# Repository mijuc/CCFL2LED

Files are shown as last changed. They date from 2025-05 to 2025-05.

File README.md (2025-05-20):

# CCFL2LED

Hi! I'm working on the R&D side of the Поново project. Through our initiative, where we upcycle old electronic devices in exchange for tree seedlings, we’ve noticed that LCD monitors are among the most common items ending up in landfills — and in our repair center as well.

Interestingly, the majority of these monitors share the same issue: the backlight. Most of them use CCFL (cold cathode fluorescent lamp) backlighting, which is often partially or completely non-functional.

As project volunteers, we concluded that replacing the CCFL lamps is not cost-effective. Instead, we aim to modernize these monitors by upgrading them to LED backlighting.

If there are any PCB design or engineering experts among you who would like to provide feedback on the design and concept — we would really appreciate it! We’d also be grateful if you could support our project by sharing it on social media or donating via [OpenCollective](https://opencollective.com/ponovo).

# Why is this change so important?

CCFL lamps are extremely harmful to the environment if broken, as they contain mercury, various metals, and plastics. They also have a significantly shorter lifespan and consume more power compared to LED technology (power consumption can be reduced by up to 40%). Controlling CCFLs requires complex electronics to drive an inverter that can generate up to 2kV AC. These circuits can degrade over time, leading to various failures, such as capacitor damage or degradation, which further impacts device operation.

Additionally, over time, CCFLs tend to yellow, giving the display a reddish or pinkish tint. That’s where LED strips come in — they are very easy to use, safer, more reliable, more available, cheaper, and longer-lasting.

# What are the results after the replacement?

The results were truly unexpected. We didn’t anticipate such a significant improvement in image quality — the colors became much more vibrant. There are no dark areas, and the light is evenly distributed across the screen. Efficiency increased, and power consumption was reduced by 30%.

# Plan and idea
The plan is to create an open-source, universal modular board for displays (composed of multiple parts/modules). This board currently combines several modules. For now, this is sufficient for us to recycle and upgrade monitors that arrive for recycling through the project [Поново](https://www.linkedin.com/company/ponovo/).

Here are picture of the working prototype (with the same chip tested on a 19", 22" and 24" display):

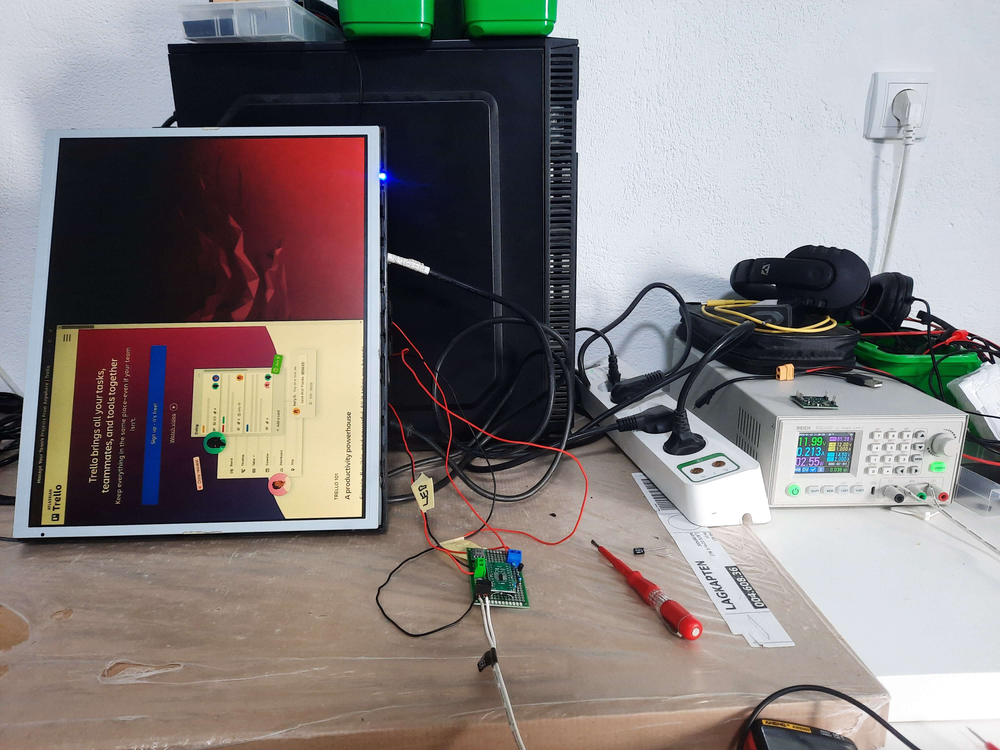
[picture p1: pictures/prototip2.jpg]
prototip2
 

# About the Board

**Warning: This particular board has not yet been fully tested! It has only been tested using separate modules.**
 * **Power supply:** USB-C PD 12V or 12V 3A barrel jack (center-positive)
 * **LED driver:** PT4115 with parallel current sense resistors, calculated based on the [datasheet](https://www.lcsc.com/datasheet/lcsc_datasheet_1810121830_PowTech-CR-PowTech-Shanghai-PT4115B89E_C84512.pdf)
 * **Buck converter:** AP62201 ([datasheet](https://www.lcsc.com/datasheet/lcsc_datasheet_2308101545_Diodes-Incorporated-AP62201WU-7_C3194236.pdf))
 * **USB Type-C PD controller:** CH224K ([datasheet](https://www.laskakit.cz/user/related_files/ch224ds1.pdf))
<p align="center">
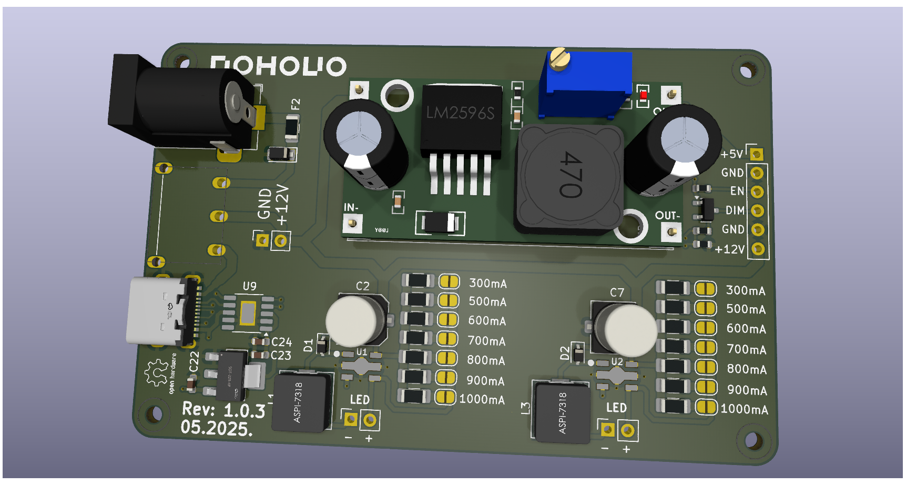
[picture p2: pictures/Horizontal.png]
  
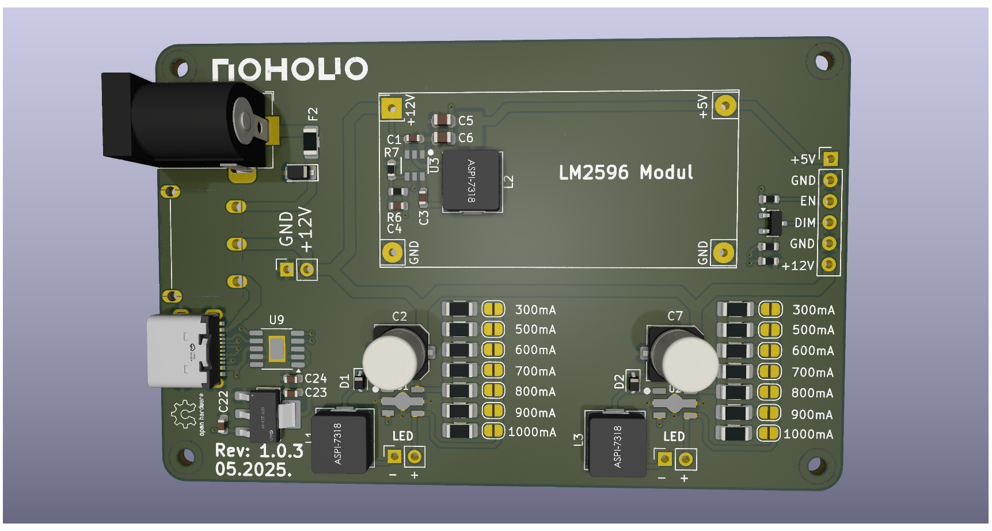
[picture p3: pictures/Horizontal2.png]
  
</p>

# Choosing an LED strip

We recommend using a strip with 120 LEDs per meter. It’s also possible to implement the mod with a 60 LEDs/m strip, but the brightness will be noticeably lower. LED's must be 6500k color. Testing of different sizes of LED strip is in progress...
# Power Supply

A maximum of 36W is required (typically around 30W depending on screen size and number of LEDs). There are two input options, selectable via a switch. The USB-C Power Delivery input uses the CH224K chip configured for a 12V output, so it's crucial to ensure that your adapter supports 12V PD — otherwise, it will not work. The second input is a standard DC jack (5.5mm outer, 2.0mm inner, center-positive) with a 12V power supply.

# LED Driver

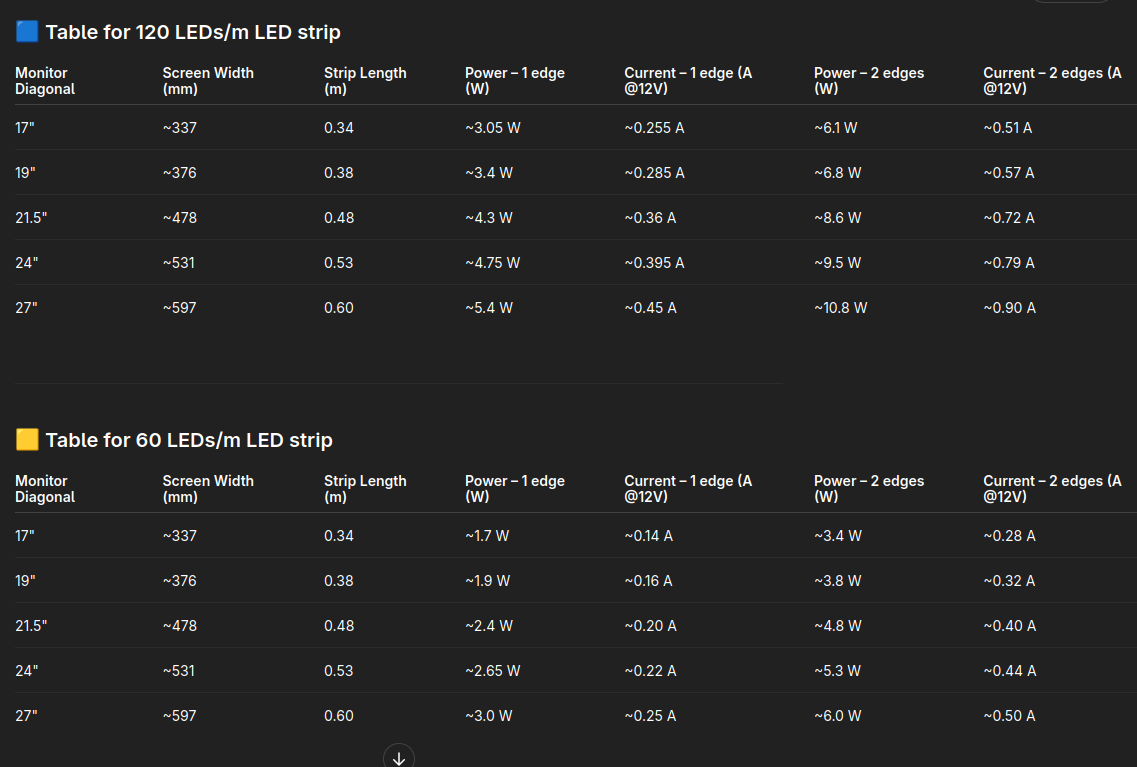
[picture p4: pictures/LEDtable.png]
TABLE
One PT4115 driver is used per side (especially important for larger screen sizes). Below is a table showing LED strip power consumption.  
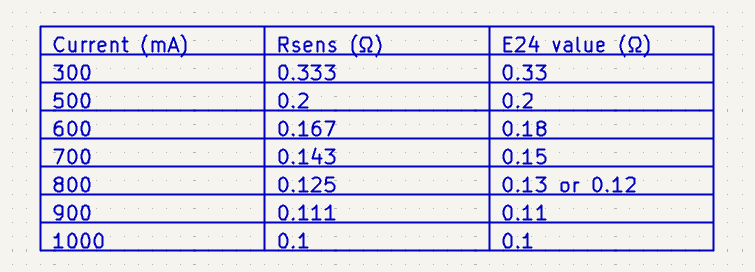
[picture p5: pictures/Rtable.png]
TABLE
Also included is a table with required resistor values. 
# Buck Converter

There are two options for the buck converter:
* Use a prebuilt LM2596 module and connect it to the board.
* Use the integrated circuit on the board — the AP62201WU-7 chip, which provides 5V for the logic board.
The maximum output power required is up to 8W at 5V.

# Modification
  **Warning: Before starting, make sure to clean the workspace and put on gloves!!!**
  
The steps we will go through in this process are:
* Carefully open the display and separate the backlight and the panel from the electronic boards.
* Continue opening the display and separate the panel from the housing, placing it in a clean area (be extremely careful during this step).
* Remove the diffusers, being careful not to mix up their order.
* Replace the CCFL (cold cathode fluorescent lamps), remove them, measure the appropriate length of LED strips, solder 30-40 cm of wire to them, and install them in place of the CCFL, then test them.
* Reinstall the diffusers and test the LED strips again to check if the diffusers have been properly returned to their place.
* Reinstall the panel (check that it is completely clean) and close that part of the display.
* Connect the LED backlight to the power supply board and link it to the display logic board.
* Test the monitor to check if all functions are working on the On-Screen Display (OSD) menu.
* Close the display and put it into operation.
- - - - 
1. **Carefully open the display and separate the backlight and the panel from the electronic boards.**

   -Be careful with the LVDS cable going to the panel
   
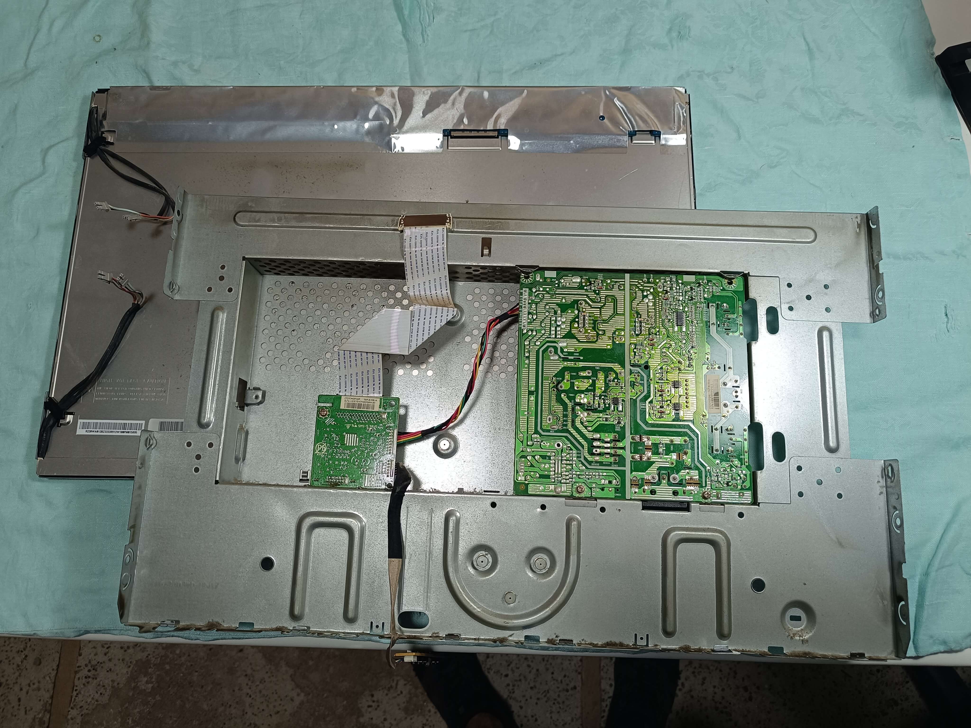
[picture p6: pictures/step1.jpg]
step1


2. **Continue opening the display and separate the panel from the housing, placing it in a clean area (be extremely careful during this step).**

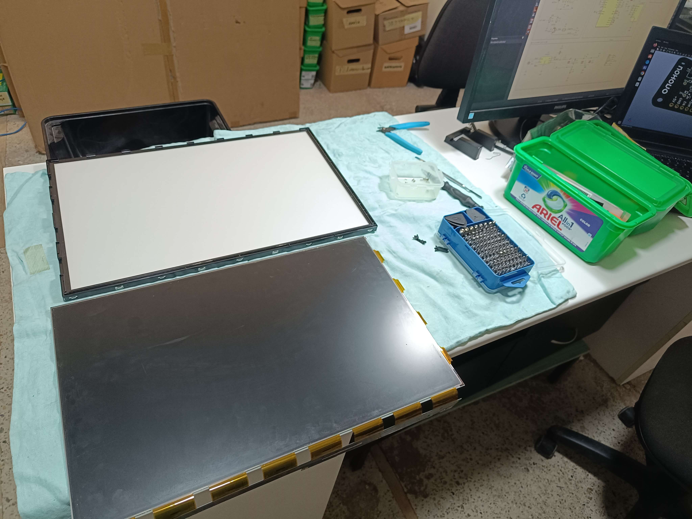
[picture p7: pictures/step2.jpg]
step2


3. **Remove the diffusers, being careful not to mix up their order.**

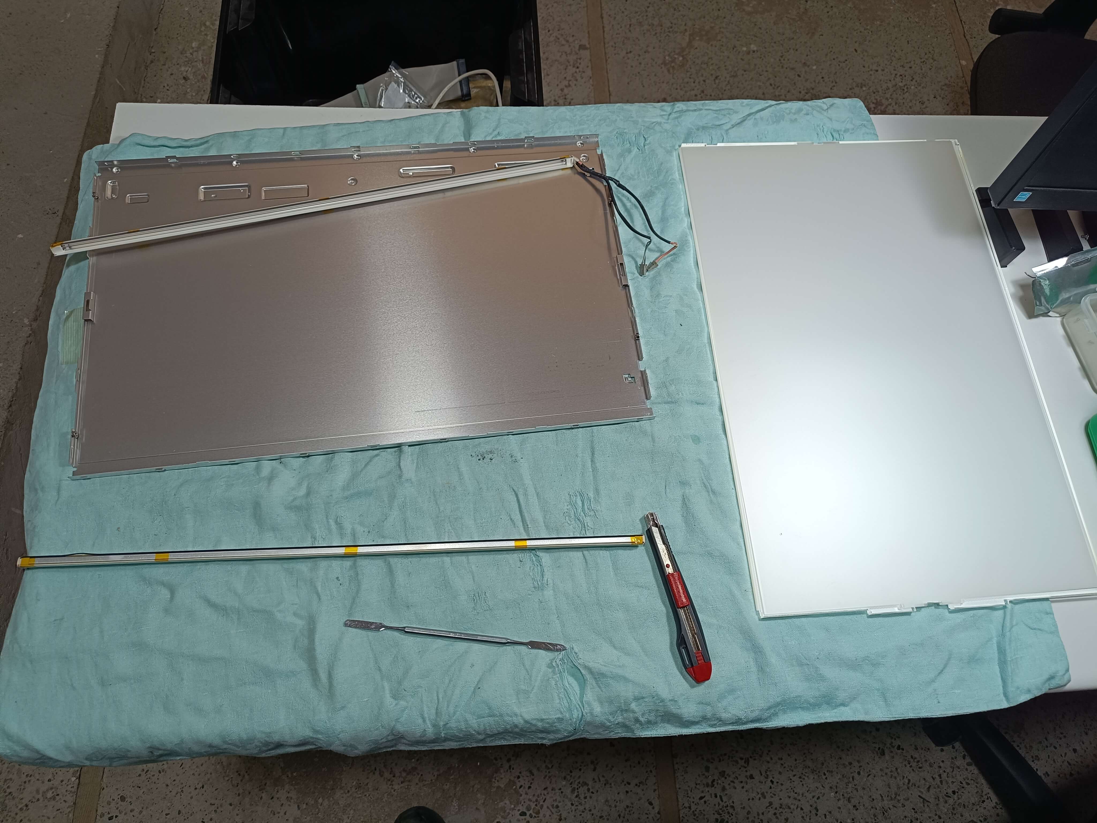
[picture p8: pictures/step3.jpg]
step3


4. **Replace the CCFL (cold cathode fluorescent lamps), remove them, measure the appropriate length of LED strips, solder 30-40 cm of wire to them, and install them in place of the CCFL, then test them.**

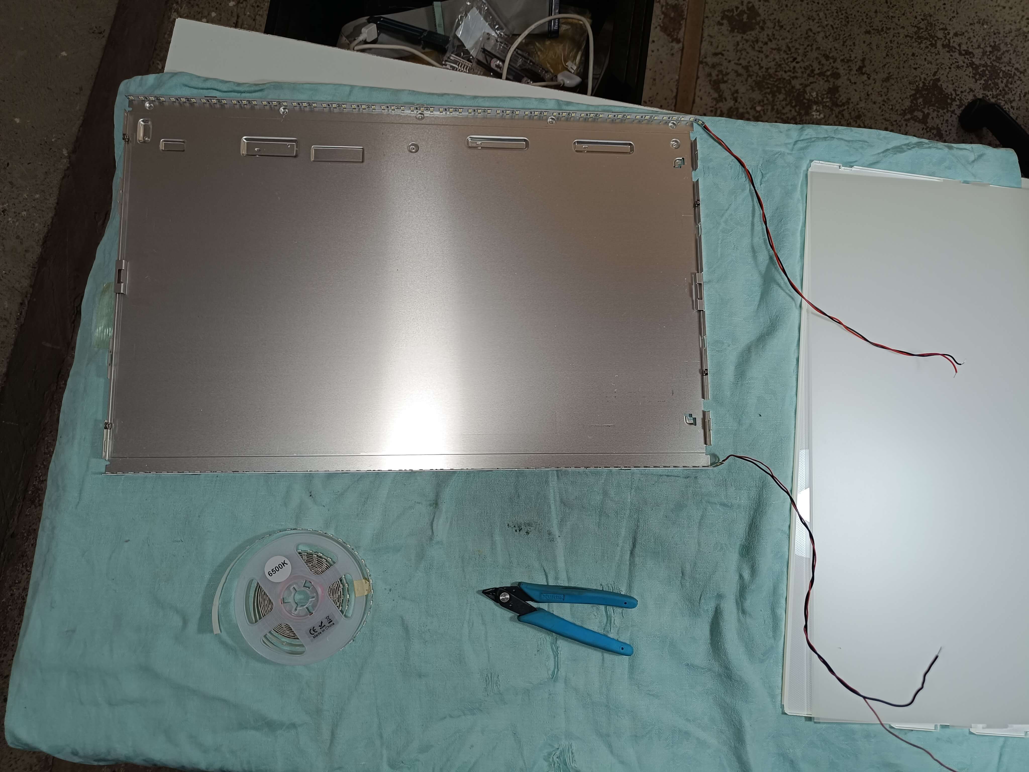
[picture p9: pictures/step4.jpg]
step4

 
 -An example of bad backlighting
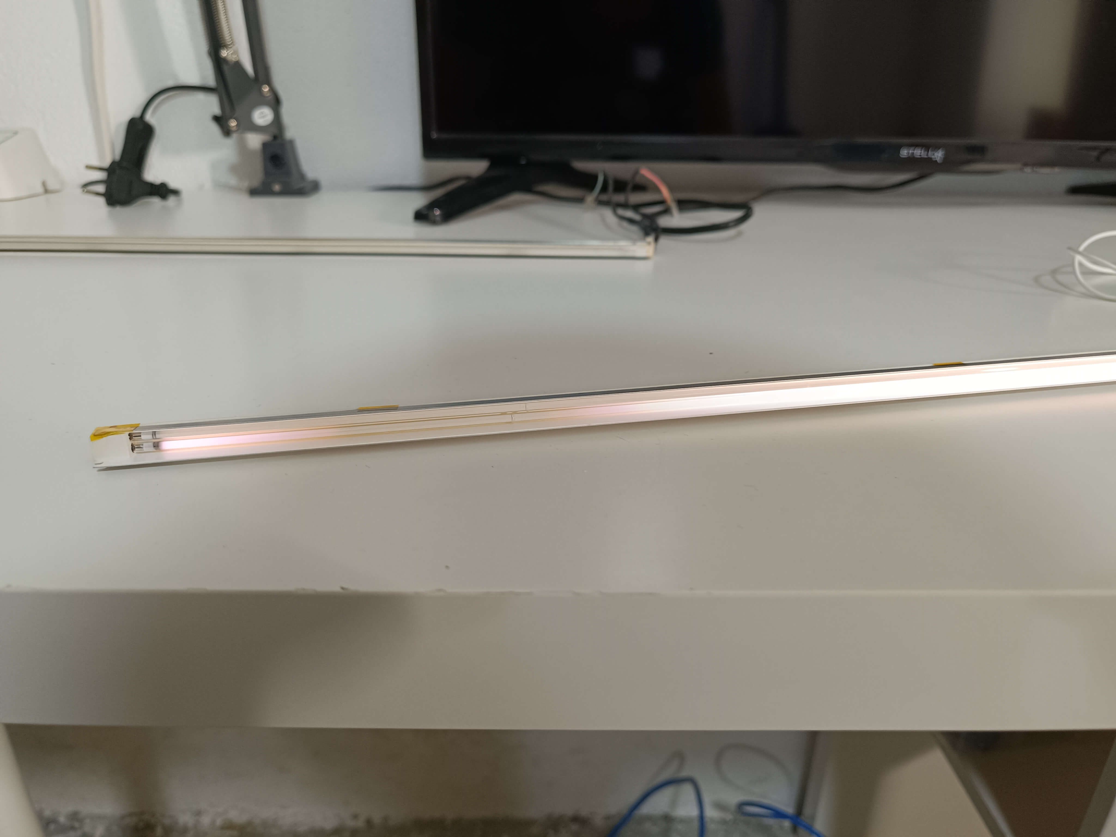
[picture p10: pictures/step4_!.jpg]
step4_!


5. **Reinstall the diffusers and test the LED strips again to check if the diffusers have been properly returned to their place.**

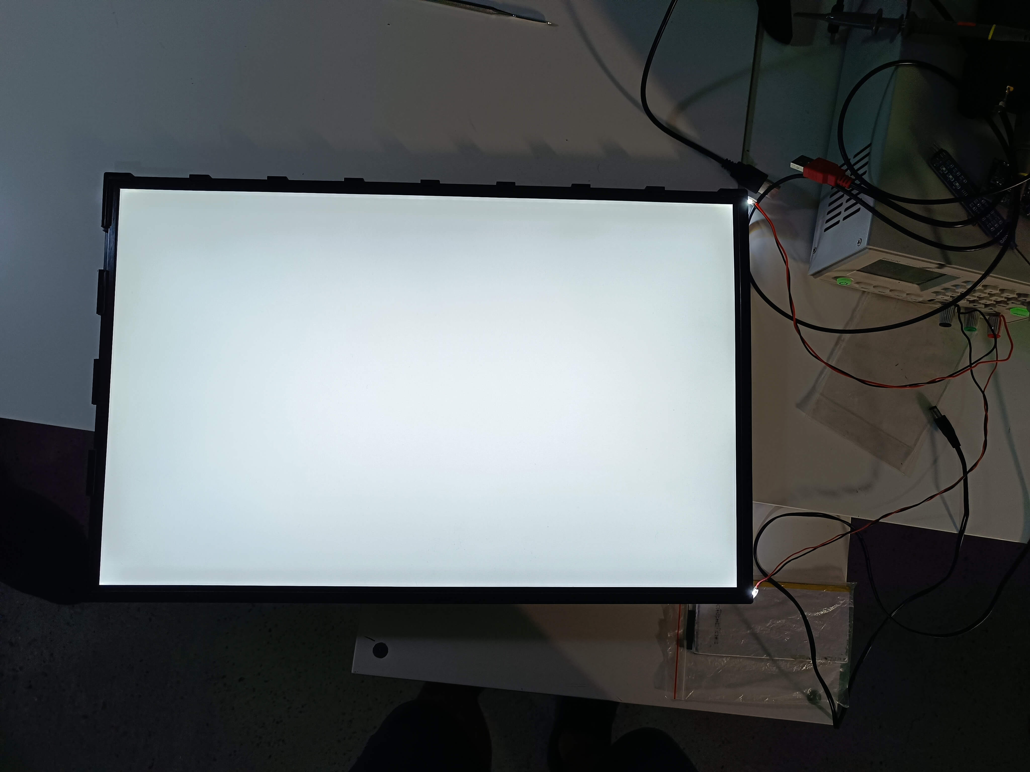
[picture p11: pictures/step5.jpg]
step5

  
  -Badly returned diffusers will have lines on the edges which is the case here
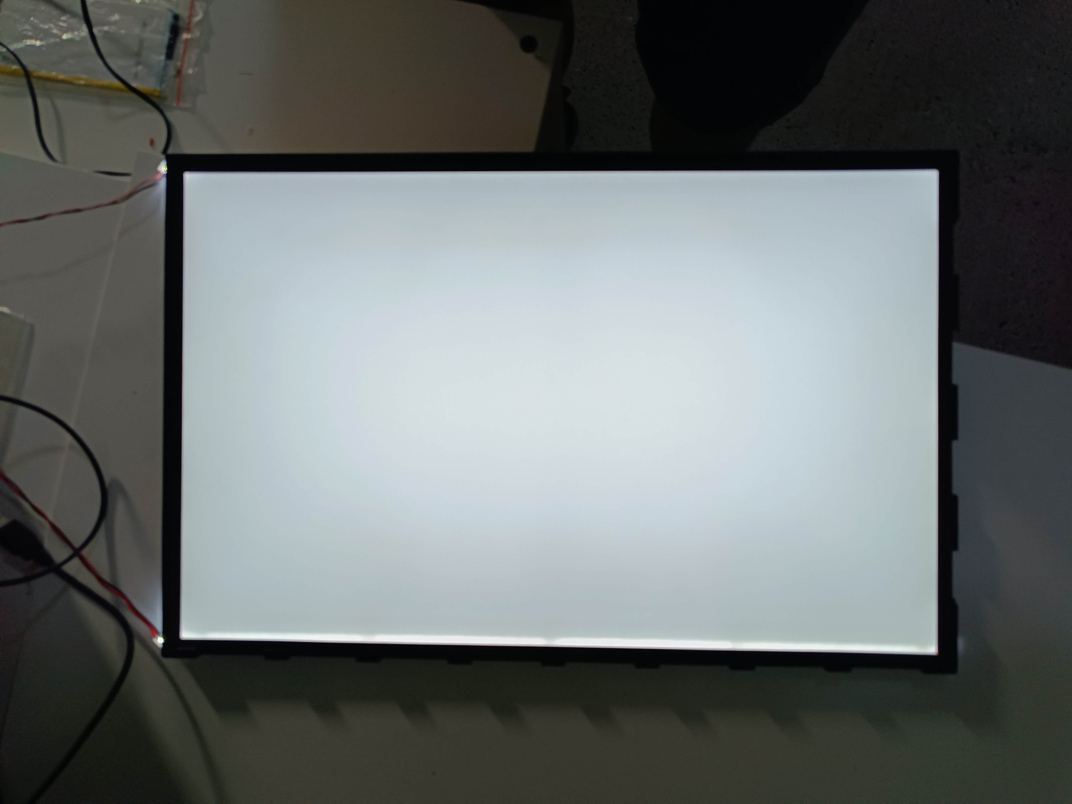
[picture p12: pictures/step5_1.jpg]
step5_1
  

6. **Reinstall the panel (check that it is completely clean) and close that part of the display.**

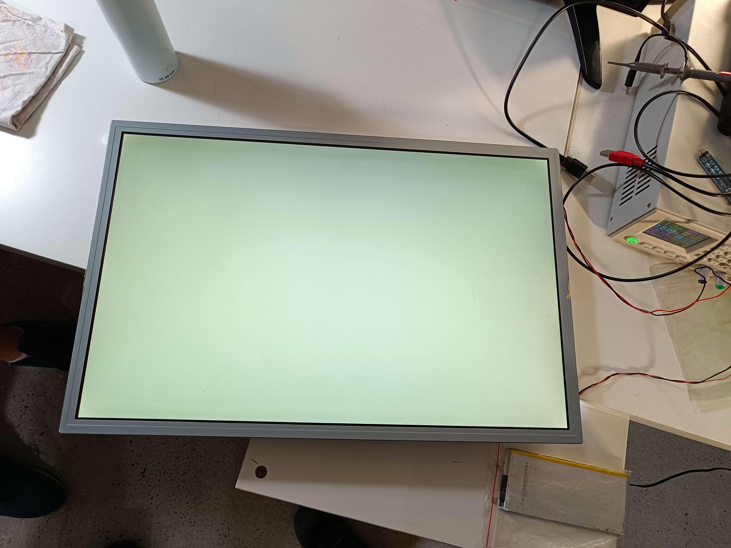
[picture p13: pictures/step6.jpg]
step6


7. **Connect the LED backlight to the power supply board and link it to the logic board of the display.**

-In this picture, the LED strips are not connected (I don't have a picture when they are connected)
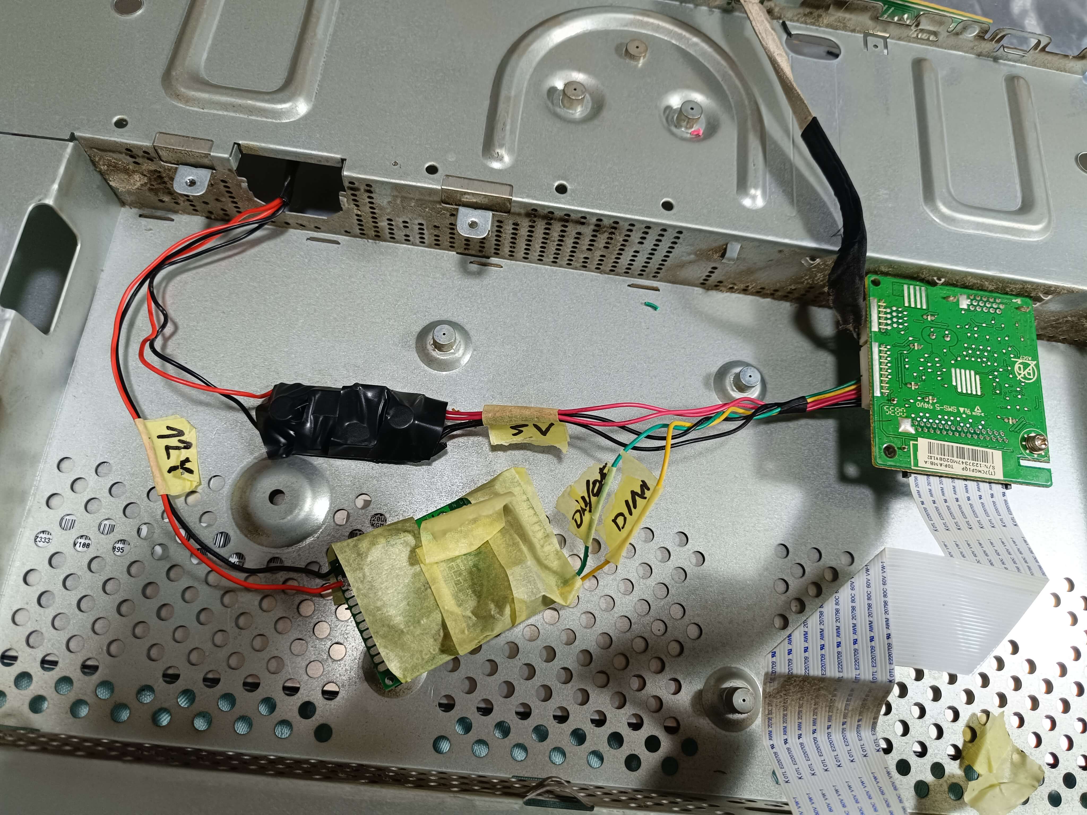
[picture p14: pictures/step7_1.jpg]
step7_1


8. **Test the monitor to check if all functions are working on the On-Screen Display (OSD) menu.**

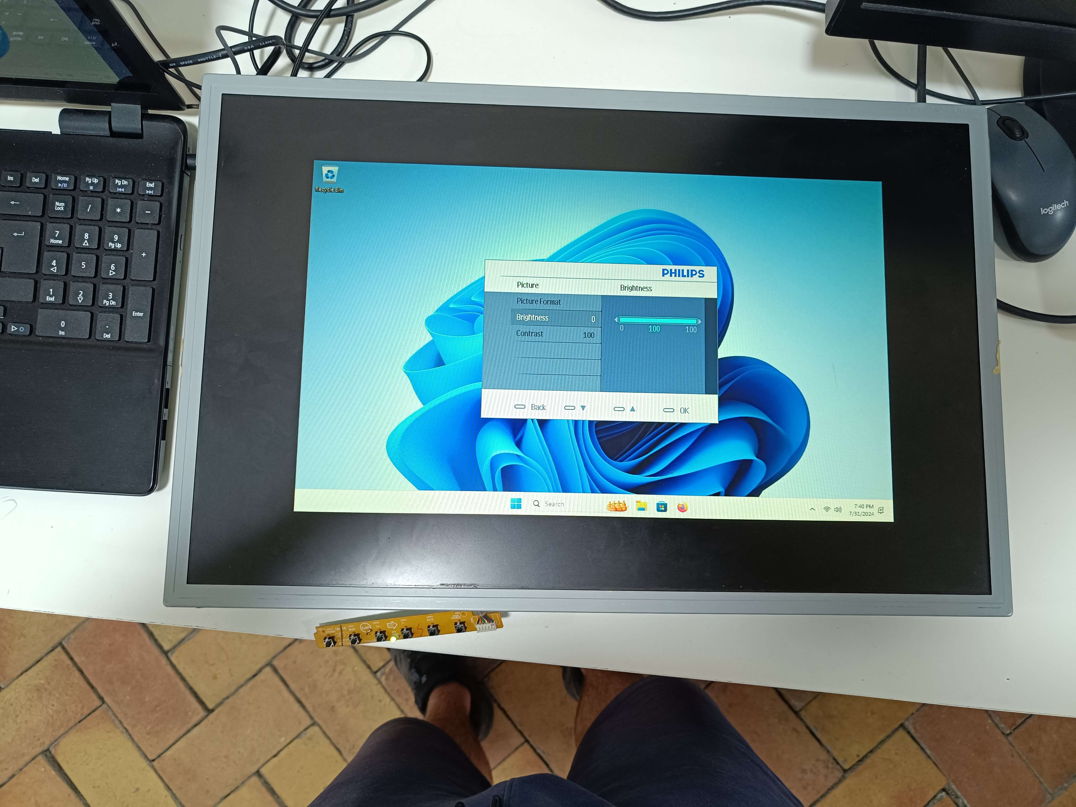
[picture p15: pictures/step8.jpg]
step8


9. **Close the display and put it into operation.**

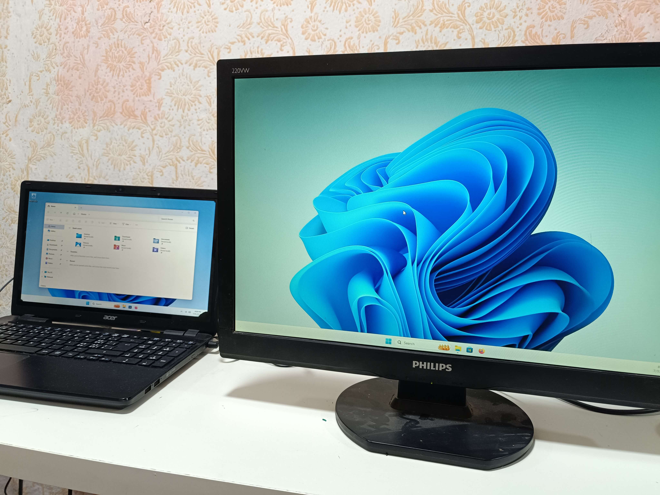
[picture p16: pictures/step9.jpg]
step9


# Next Steps
  * AC/DC Converter (230V AC to 12V DC)
  * Open-source universal logic board for monitors
# Contact
* Matrix - [@vladanm](https://matrix.to/#/@vladanm:matrix.org)
* LinkedIn - [Vladan Mijuc](https://www.linkedin.com/in/vladan-mijuc-bab922198/)
* Mail - mijuc.edu@gmail.com

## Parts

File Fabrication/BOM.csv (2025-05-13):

Reference | Qty | Value | Footprint | LCSC Part # | LCSC
C1 | 1 | 10uF | PCM_JLCPCB:C_0603 | C1713 | C96446
C2,C7 | 2 | 100uF | Capacitor_SMD:C_Elec_6.3x7.7 | C7432790 | C7432790
C3 | 1 | 100nF | PCM_JLCPCB:C_0603 | C66501 | C14663
C4 | 1 | 100pF | PCM_JLCPCB:C_0603 | C519407 | C14858
C5,C6 | 2 | 22uF | PCM_JLCPCB:C_0805 | C98190 | C45783
C22,C23 | 2 | 10uF | PCM_JLCPCB:C_0603 | C96446 | C96446
C24 | 1 | 1uF | PCM_JLCPCB:C_0603 | C15849 | C15849
D1,D2 | 2 | 1N5819WS | Diode_SMD:D_SOD-323 | C2828425 | C2828425
D3 | 1 | SD12CT1G | PCM_JLCPCB:D_SOD-123FL | C2985489 | C19077508
F2 | 1 | CFS12V6T2R0 | Fuse:Fuse_1206_3216Metric | C163132 | C163132
J2 | 1 | USB_C_Receptacle_USB2.0_16P | PCM_JLCPCB:TYPE-C-SMD_HX-TYPE-C-16PIN | C2927039 | C2927039
J3 | 1 | Jack-DC | Connector_BarrelJack:BarrelJack_Horizontal | C3010534 | C3010534
J5,J6,J7 | 3 | Conn_01x02_Pin | Connector_PinSocket_2.54mm:PinSocket_1x02_P2.54mm_Vertical
L1,L3 | 2 | 33uH | Inductor_SMD:L_7.3x7.3_H4.5 | C5189937 | C5189937
L2 | 1 | 4u7H | Inductor_SMD:L_7.3x7.3_H4.5 | C5189748 | C5189748
Q1 | 1 | S8050 | PCM_JLCPCB:Q_SOT-23 | C18221467 | C364312
R1,R7 | 2 | 10K | PCM_JLCPCB:R_0603 | C25804 | C25804
R2,R5 | 2 | 1K | PCM_JLCPCB:R_0603 | C22548 | C21190
R3,R13 | 2 | 0.33R | Resistor_SMD:R_1206_3216Metric_Pad1.30x1.75mm_HandSolder | C341598 | C341598
R4,R14 | 2 | 0.2R | Resistor_SMD:R_1206_3216Metric_Pad1.30x1.75mm_HandSolder | C160920 | C160920
R6 | 1 | 52K3 | PCM_JLCPCB:R_0603 | C2933235 | C23196
R8,R15 | 2 | 0.18R | Resistor_SMD:R_1206_3216Metric_Pad1.30x1.75mm_HandSolder | C912784 | C912784
R9,R16 | 2 | 0.15R | Resistor_SMD:R_1206_3216Metric_Pad1.30x1.75mm_HandSolder | C2991747 | C2991747
R10,R17 | 2 | 0.13R | Resistor_SMD:R_1206_3216Metric_Pad1.30x1.75mm_HandSolder | C2683382 | C2683382
R11,R18 | 2 | 0.11R | Resistor_SMD:R_1206_3216Metric_Pad1.30x1.75mm_HandSolder | C82532 | C82532
R12,R19 | 2 | 0.1R | Resistor_SMD:R_1206_3216Metric_Pad1.30x1.75mm_HandSolder | C188071 | C188071
SW1 | 1 | SW_SPDT | CustomSwitchFootprint:SS-12D11-G7 | C17179526 | C17179526
U1,U2 | 2 | PT4115 | LED_Driver_Global:SOT-89-5 | C347356 | C347356
U3 | 1 | AP62201WU-7 | Buck_Converters_Global:TSOT26-WU_DIO | C3194236 | C3194236
U7 | 1 | LM2596 Modul | Buck_Converters_Global:YAAJ_DCDC_StepDown_LM2596
U8 | 1 | AMS1117-3.3 | PCM_JLCPCB:SOT-223-3_L6.5-W3.4-P2.30-LS7.0-BR | C6186 | C6186
U9 | 1 | CH224K | Package_SO:SSOP-10-1EP_3.9x4.9mm_P1mm_EP2.1x3.3mm | C970725 | C970725

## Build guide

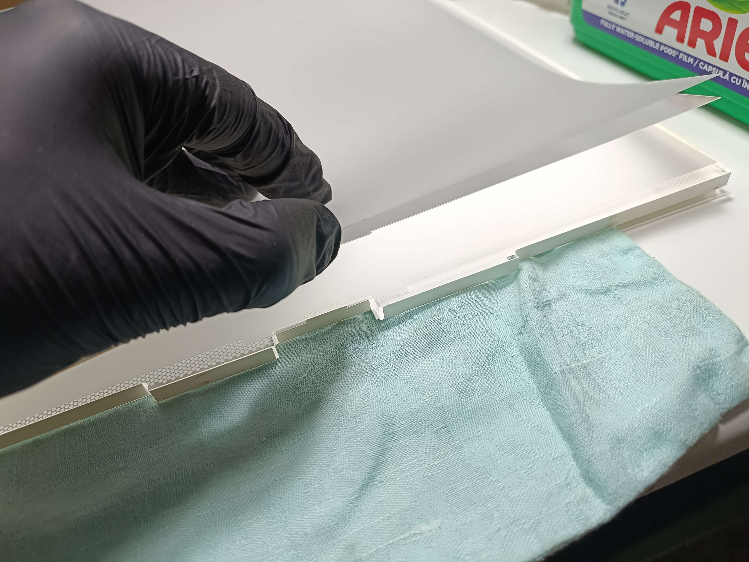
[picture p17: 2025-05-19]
pictures/step3_1.jpg

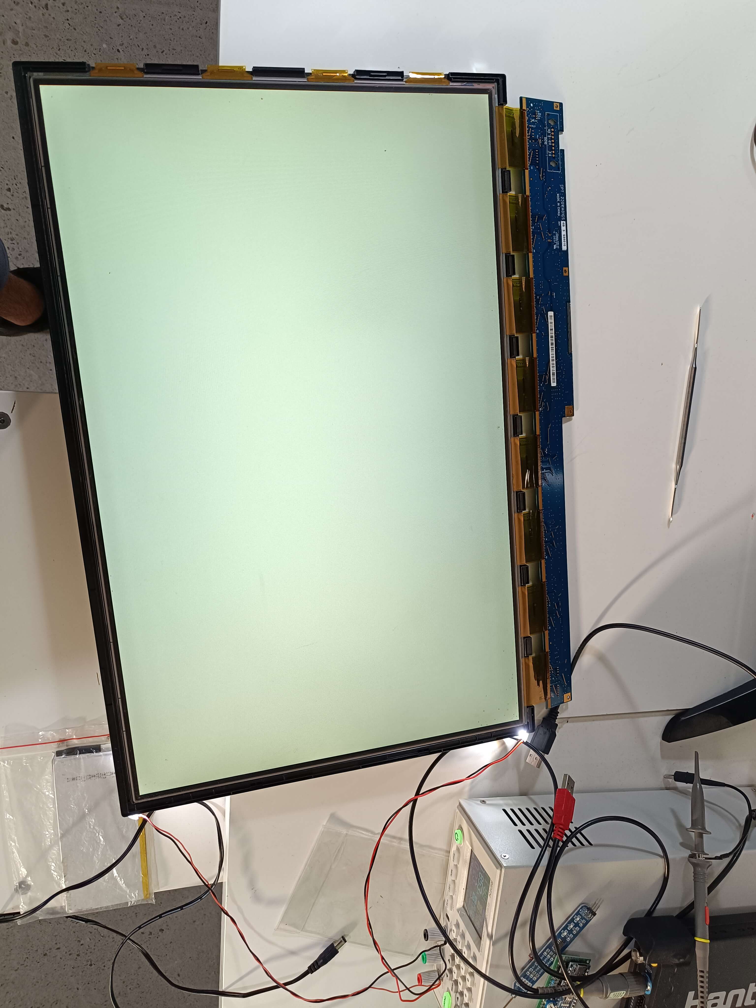
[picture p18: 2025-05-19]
pictures/step6_1.jpg

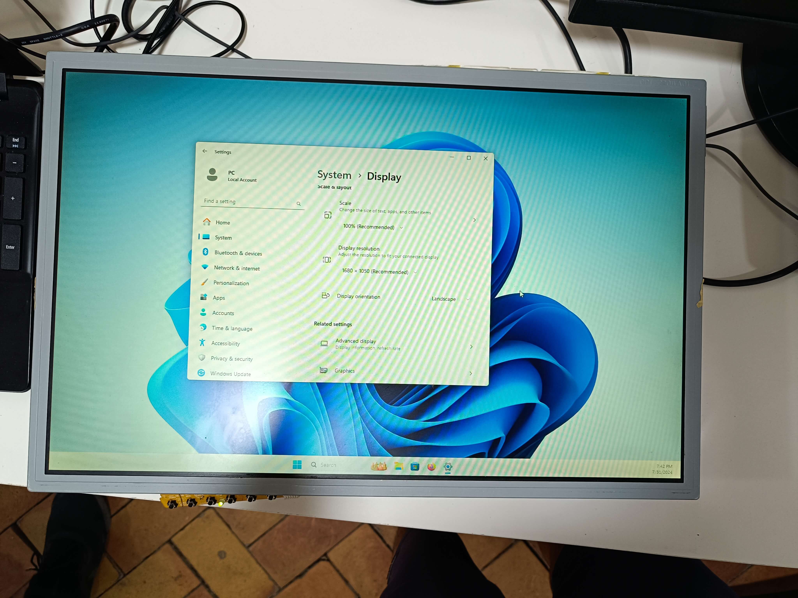
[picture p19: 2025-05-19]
pictures/step8_1.jpg

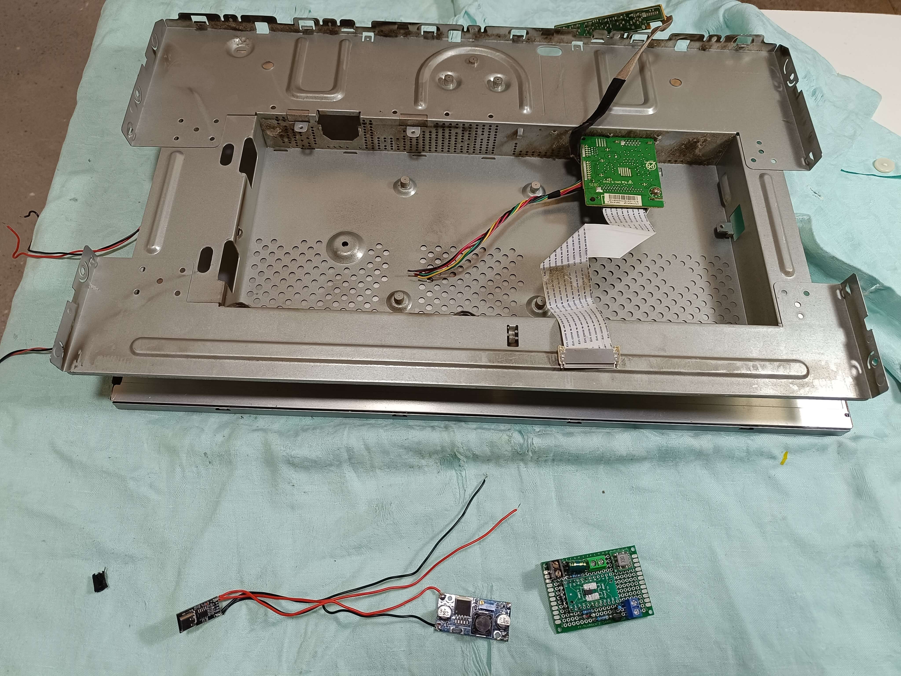
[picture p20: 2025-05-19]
pictures/step7.jpg

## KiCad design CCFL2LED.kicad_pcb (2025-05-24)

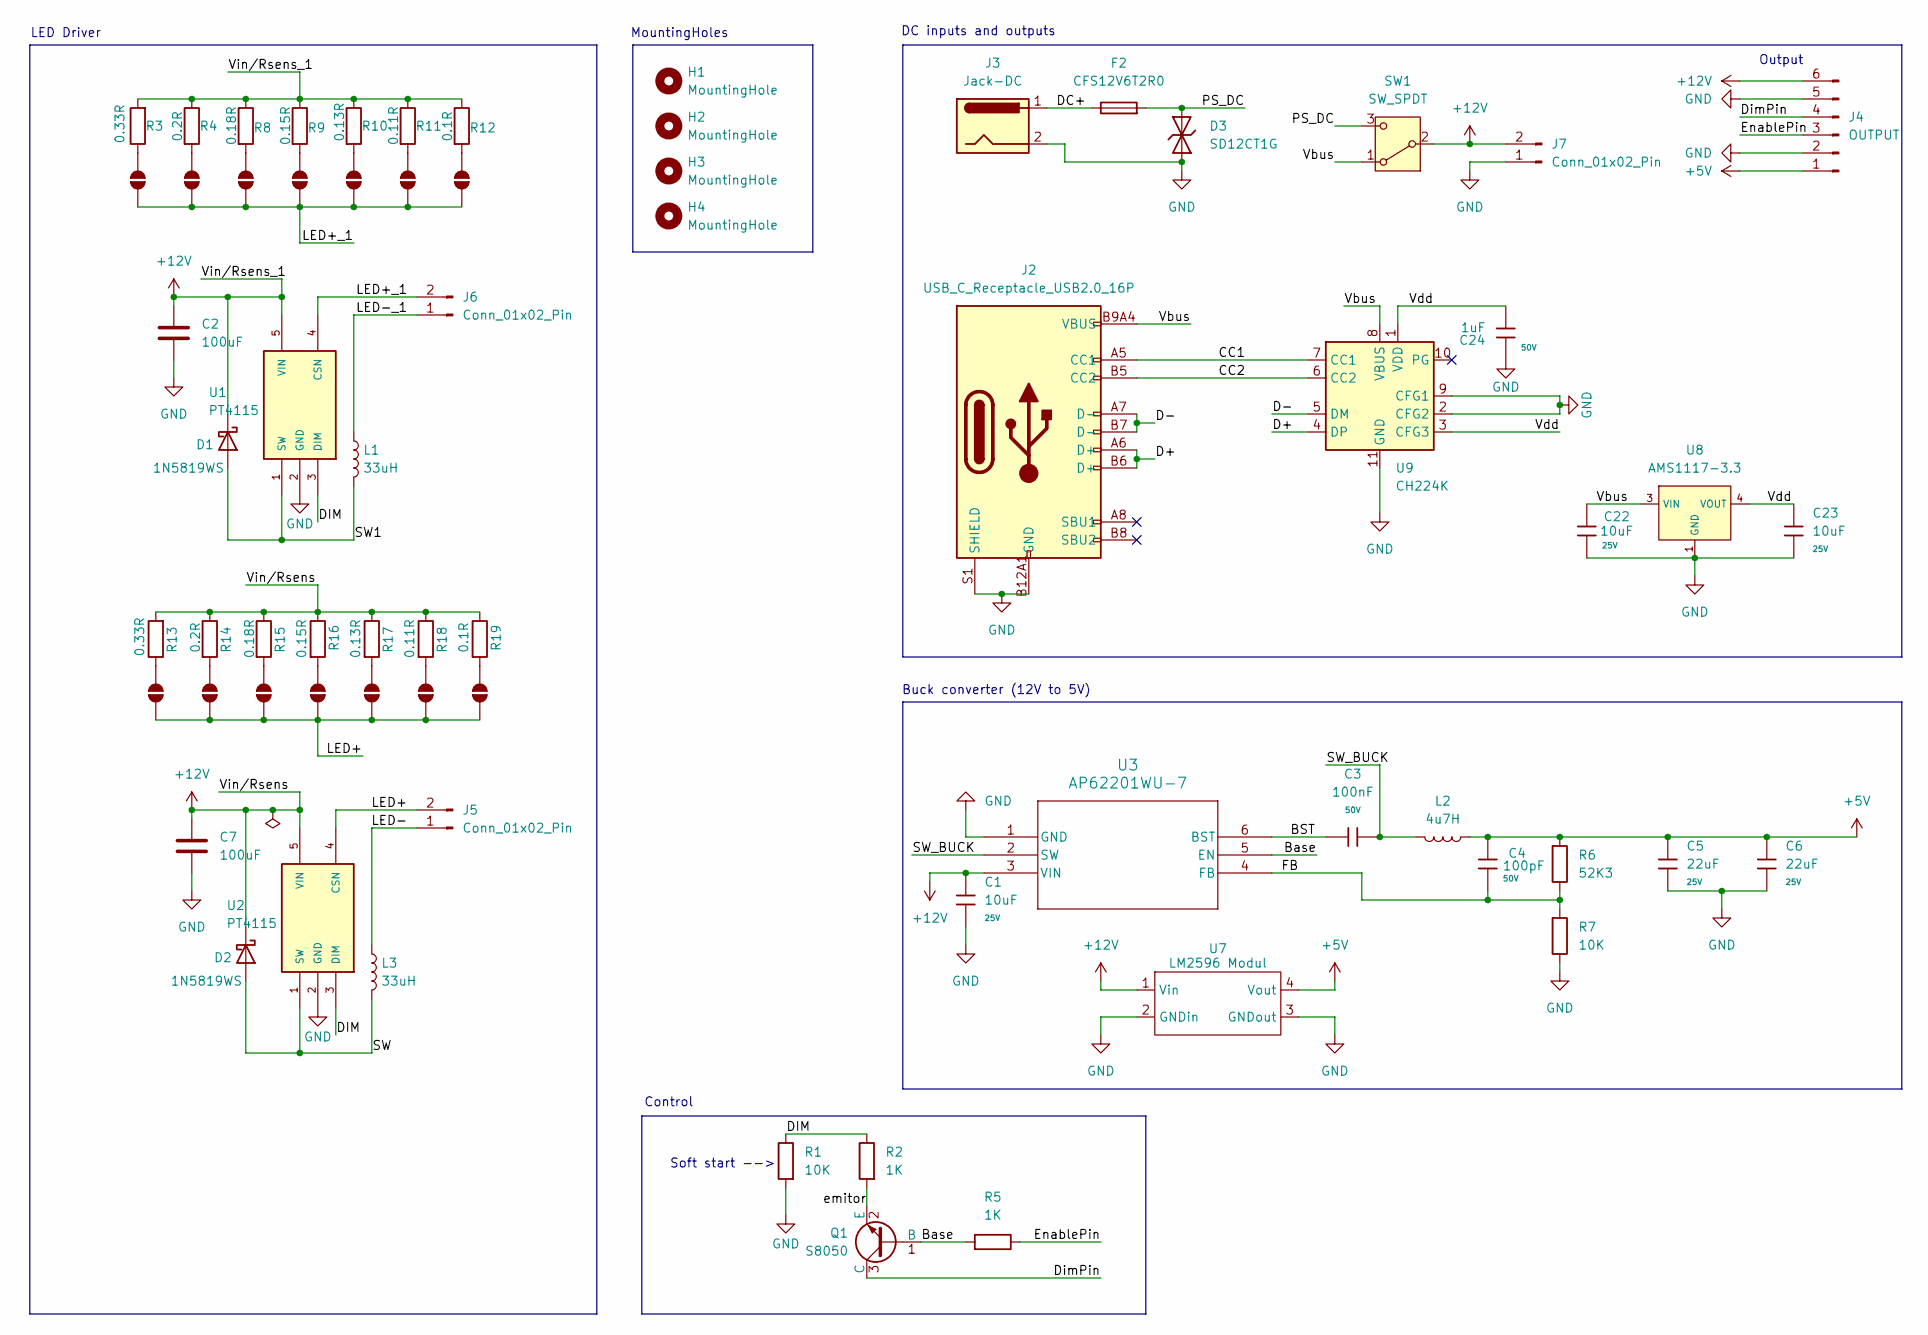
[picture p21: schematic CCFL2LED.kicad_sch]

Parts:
C1: 10uF; C_0603; Voltage Rated 25V; Tolerance ±20%; Part CL10A106MA8NRNC; LCSC Part # C1713
C2, C7: 100uF; C_Elec_6.3x7.7; LCSC Part # C7432790
C3: 100nF; C_0603; Voltage Rated 50V; Tolerance ±10%; Part CC0603KRX7R9BB104; LCSC Part # C66501
C4: 100pF; C_0603; Voltage Rated 50V; Tolerance ±5%; Part CL10C101JB8NNNC; LCSC Part # C519407
C5, C6: 22uF; C_0805; Voltage Rated 25V; Tolerance ±20%; Part CL21A226MAQNNNE; LCSC Part # C98190
C22: 10uF; C_0603; Voltage Rated 25V; Tolerance ±20%; Part CL10A106MA8NRNC; LCSC C96446
C23: 10uF; C_0603; Voltage Rated 25V; Tolerance ±20%; Part CL10A106MA8NRNC; LCSC Part # C96446
C24: 1uF; C_0603; Voltage Rated 50V; Tolerance ±10%; Part CL10A105KB8NNNC; LCSC C15849
D1, D2: 1N5819WS; D_SOD-323; LCSC Part # C2828425
D3: SD12CT1G; D_SOD-123FL; Part SMF13CA; LCSC Part # C2985489
F2: CFS12V6T2R0; Fuse_1206_3216Metric; LCSC Part # C163132
H1, H2, H3, H4: MountingHole; MountingHole_2.2mm_M2
J2: USB_C_Receptacle_USB2.0_16P; TYPE-C-SMD_HX-TYPE-C-16PIN; LCSC C2927039
J3: Jack-DC; BarrelJack_Horizontal; LCSC Part # C720557
J4: OUTPUT; PinHeader_1x06_P2.54mm_Vertical
J5, J6, J7: Conn_01x02_Pin; PinSocket_1x02_P2.54mm_Vertical
JP1, JP2, JP3, JP4, JP5, JP6, JP7, JP8, JP9, JP10, JP11, JP12, JP13, JP14: SolderJumper_2_Open; SolderJumper-2_P1.3mm_Open_RoundedPad1.0x1.5mm
L1, L3: 33uH; L_7.3x7.3_H4.5; LCSC Part # C5189937
L2: 4u7H; L_7.3x7.3_H4.5; LCSC Part # C5189748
Q1: S8050; Q_SOT-23; Part S8050; LCSC Part # C18221467
R1, R7: 10K; R_0603; Overload Voltage (Max) 75V; Tolerance ±1%; Part 0603WAF1002T5E; LCSC Part # C25804
R2, R5: 1K; R_0603; Overload Voltage (Max) 75V; Tolerance ±1%; Part 0603WAF1001T5E; LCSC Part # C22548
R3, R13: 0.33R; R_1206_3216Metric_Pad1.30x1.75mm_HandSolder; LCSC C341598
R4, R14: 0.2R; R_1206_3216Metric_Pad1.30x1.75mm_HandSolder; LCSC C160920
R6: 52K3; R_0603; Overload Voltage (Max) 75V; Tolerance ±1%; Part 0603WAF5102T5E; LCSC Part # C2933235
R8, R15: 0.18R; R_1206_3216Metric_Pad1.30x1.75mm_HandSolder; LCSC C912784
R9, R16: 0.15R; R_1206_3216Metric_Pad1.30x1.75mm_HandSolder; LCSC C2991747
R10, R17: 0.13R; R_1206_3216Metric_Pad1.30x1.75mm_HandSolder; LCSC C2683382
R11, R18: 0.11R; R_1206_3216Metric_Pad1.30x1.75mm_HandSolder; LCSC C82532
R12, R19: 0.1R; R_1206_3216Metric_Pad1.30x1.75mm_HandSolder; LCSC C188071
SW1: SW_SPDT; SS-12D11-G7; LCSC C17179526
U1, U2: PT4115; SOT-89-5; LCSC C347356
U3: AP62201WU-7; TSOT26-WU_DIO; LCSC Part C3194236
U7: LM2596 Modul; YAAJ_DCDC_StepDown_LM2596
U8: AMS1117-3.3; SOT-223-3_L6.5-W3.4-P2.30-LS7.0-BR; Output Voltage 3.3V; Dropout Voltage 1.3V@(800mA); Part AMS1117-3.3; LCSC C6186
U9: CH224K; SSOP-10-1EP_3.9x4.9mm_P1mm_EP2.1x3.3mm; LCSC C970725

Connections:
+5V: C4.1, C5.1, C6.1, J4.1, L2.1, R6.1, U7.4 (Vout)
+12V: C1.2, C2.1, C7.1, D1.1 (K), D2.1 (K), J4.6, J7.2, R3.2, R4.1, R8.1, R9.1, R10.1, R11.1, R12.1, R13.2, R14.1, R15.1, R16.1, R17.1, R18.1, R19.1, SW1.2 (B), U1.5 (VIN), U2.5 (VIN), U3.3 (VIN), U7.1 (Vin)
/BST: C3.1, U3.6 (BST)
/Base: Q1.1 (B), R5.1, U3.5 (EN)
/CC1: J2.A5 (CC1), U9.7 (CC1)
/CC2: J2.B5 (CC2), U9.6 (CC2)
/D+: J2.A6 (D+), J2.B6 (D+), U9.4 (DP)
/D-: J2.A7 (D-), J2.B7 (D-), U9.5 (DM)
/DC+: F2.1, J3.1
/DIM: R1.2, R2.2, U1.3 (DIM), U2.3 (DIM)
/DimPin: J4.4, Q1.3 (C)
/EnablePin: J4.3, R5.2
/FB: C4.2, R6.2, R7.1, U3.4 (FB)
/LED+: J5.2, JP8.1 (A), JP9.1 (A), JP10.1 (A), JP11.1 (A), JP12.1 (A), JP13.1 (A), JP14.1 (A), U2.4 (CSN); also elsewhere on the board
/LED+_1: J6.2, JP1.1 (A), JP2.1 (A), JP3.1 (A), JP4.1 (A), JP5.1 (A), JP6.1 (A), JP7.1 (A), U1.4 (CSN); also elsewhere on the board
/LED-: J5.1, L3.1; also elsewhere on the board
/LED-_1: J6.1, L1.1; also elsewhere on the board
/PS_DC: D3.1, F2.2, SW1.3 (C)
/SW: D2.2 (A), L3.2, U2.1 (SW)
/SW1: D1.2 (A), L1.2, U1.1 (SW)
/SW_BUCK: C3.2, L2.2, U3.2 (SW)
/Vbus: C22.1, J2.A9B4 (VBUS), J2.B9A4 (VBUS), SW1.1 (A), U8.3 (VIN), U9.8 (VBUS)
/Vdd: C23.1, C24.1, U8.2 (VOUT), U8.4 (VOUT), U9.1 (VDD), U9.3 (CFG3)
/emitor: Q1.2 (E), R2.1
GND: C1.1, C2.2, C5.2, C6.2, C7.2, C22.2, C23.2, C24.2, D3.2, J2.A12B1 (GND), J2.B12A1 (GND), J2.S1 (SHIELD), J3.2, J4.2, J4.5, J7.1, R1.1, R7.2, U1.2 (GND), U2.2 (GND), U3.1 (GND), U7.2 (GNDin), U7.3 (GNDout), U8.1 (GND), U9.2 (CFG2), U9.9 (CFG1), U9.11 (GND)
unnamed: JP1.2 (B), R3.1
unnamed: JP2.2 (B), R4.2
unnamed: JP3.2 (B), R8.2
unnamed: JP4.2 (B), R9.2
unnamed: JP5.2 (B), R10.2
unnamed: JP6.2 (B), R11.2
unnamed: JP7.2 (B), R12.2
unnamed: JP8.2 (B), R13.1
unnamed: JP9.2 (B), R14.2
unnamed: JP10.2 (B), R15.2
unnamed: JP11.2 (B), R16.2
unnamed: JP12.2 (B), R17.2
unnamed: JP13.2 (B), R18.2
unnamed: JP14.2 (B), R19.2

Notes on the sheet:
Buck converter (12V to 5V)
LED Driver
Control
Soft start -->
MountingHoles
Output
DC inputs and outputs

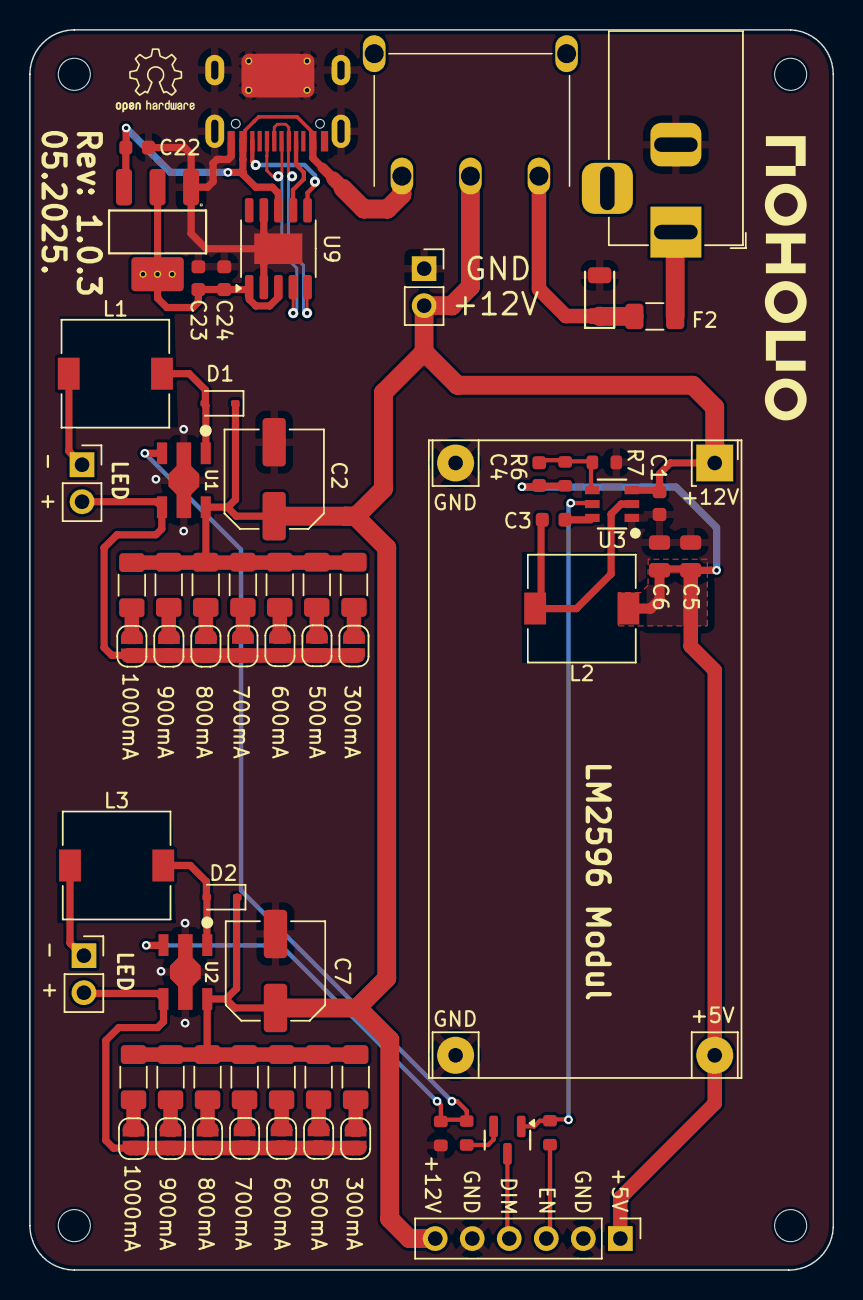
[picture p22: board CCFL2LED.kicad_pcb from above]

Board: 2 copper layers, 55.1 x 85.1 mm, 68 parts (0 on the bottom side), 39 nets.

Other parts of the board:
+  -: Conn_01x02_Pin; PinSocket_1x02_P2.54mm_Vertical
+  -#2: Conn_01x02_Pin; PinSocket_1x02_P2.54mm_Vertical

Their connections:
/LED+: + -#2.2; also elsewhere on the board
/LED+_1: + -.2; also elsewhere on the board
/LED-: + -#2.1; also elsewhere on the board
/LED-_1: + -.1; also elsewhere on the board

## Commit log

2025-05-13 1.0.3 Version files
    [BOM.csv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]
2025-05-19 Update schematic and pictures
    [CCFL2LED.kicad_sch]
2025-05-24 Trace update
    - Update pictures
    - Update kicad_pcb
    - Update fabrication files
    [CCFL2LED-B_Cu.gbl, CCFL2LED-B_Mask.gbs, CCFL2LED-B_Paste.gbp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]
